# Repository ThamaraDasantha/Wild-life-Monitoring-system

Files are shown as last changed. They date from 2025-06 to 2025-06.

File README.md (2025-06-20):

# 🐾 Wildlife Monitoring System for Development in Tourism

This project introduces a **solar-powered, real-time wildlife monitoring system** that enhances tourism by providing live animal detection, classification, and notifications through a mobile app. The system leverages edge computing, AI, and long-range wireless communication to deliver efficient and scalable wildlife monitoring in remote areas.

---

## 🎯 Project Objectives

- Boost eco-tourism by enabling real-time wildlife sightings.
- Enhance conservation through automated monitoring.
- Provide a user-friendly experience via a dedicated mobile application.
- Support wildlife-related research and law enforcement with data analytics.

---

## 🔧 Key Technologies

| Feature | Description |
|---|---|
| **Animal Detection** | Real-time CNN-based species classification on captured images |
| **Edge Computing** | Raspberry Pi Zero2W perform local processing |
| **Power Management** | STM32 Microcontorller for Power Management |
| **Power Source** | Solar-powered units with rechargeable backup batteries |
| **Communication** | Long-range LoRa WAN to central hub, Bluetooth for mobile device connection |
| **Mobile App** | Displays animal sightings, real-time alerts, navigation support |
| **Smart Algorithms** | Optimizes vehicle paths for tourist flow, efficiency, and safety |
| **Database Integration** | Centralized storage for research, anti-poaching, and wildlife conflict prevention |

---

## 📐 System Architecture

```
[Motion Sensor] ──> [STM32] ──> [Raspberry Pi] ──> CNN [Local Decision Making]
                                   ↓
                            LoRa Transmission
                                   ↓
                            [Central Hub] ──>[Database]
                                   ↓
                            [Vehical Module (Lora to Blutooth Interfacing)]
                                   ↓
                             [App Backend]
```

---

## 📲 Mobile Application Features

- 📸 Live animal detection alerts
- 📍 Wildlife location navigation
- 🐅 Animal type filter & sighting history
- 🌐 Connected via Bluetooth to nearby monitoring nodes or central hub

---

## 🌍 Real-World Impact

- **Tourism**: Improves visitor experience with real-time encounters.
- **Research**: Data logging enables pattern analysis and habitat studies.
- **Conservation**: Supports anti-poaching strategies and conflict mitigation.
- **Sustainability**: Operates off-grid using solar energy.

---

## 👥 Authors & Acknowledgments

- **Thamara Banneheka**, ** Isuru Abhayarathne**, **Dinith Wanniarachchi**  
  Department of Electrical and Electronic Engineering, SLIIT  
- Supervised by: *Shehani Jayasinghe, Dr. Eranga Wijesinghe, Dr. Nushara Wedasingha*

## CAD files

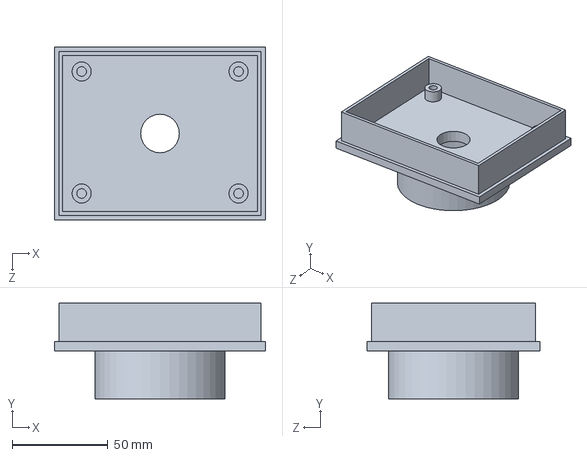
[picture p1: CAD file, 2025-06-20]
Tracker Module/Enclouser/Traker module.SLDASM
110.0 x 50.0 x 90.0 mm

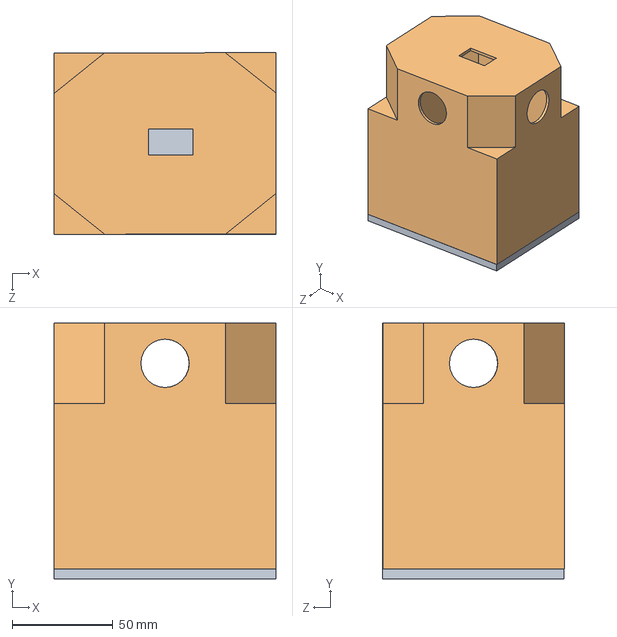
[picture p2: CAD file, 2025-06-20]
Tracker Module/Enclouser/Assem1.SLDASM
110.1 x 127.0 x 90.1 mm
BOTTOM_Part
TOP_PART

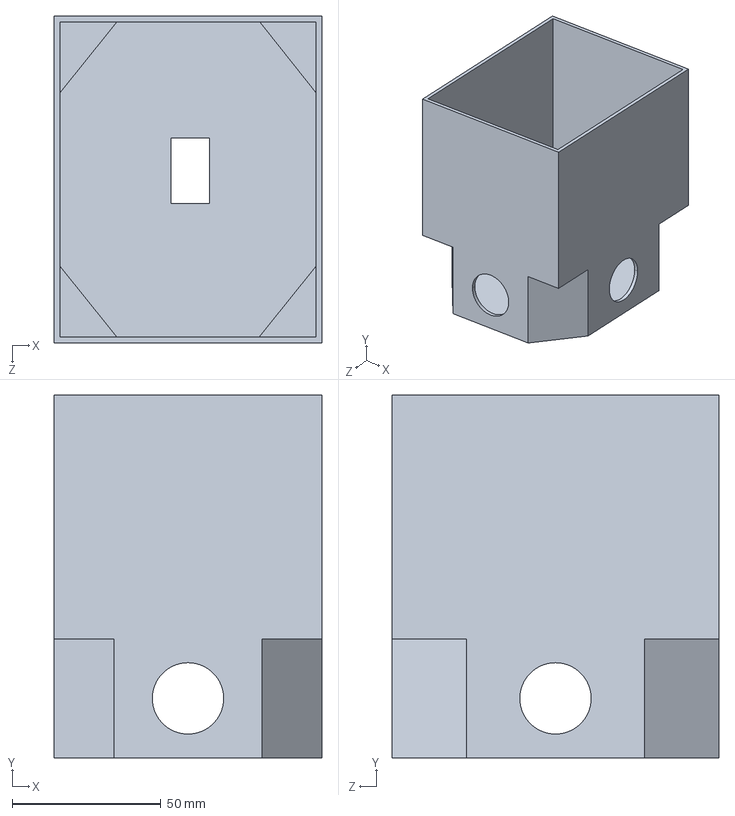
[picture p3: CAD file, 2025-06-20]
Tracker Module/Enclouser/TOP_PART.STEP
90.0 x 122.0 x 110.0 mm

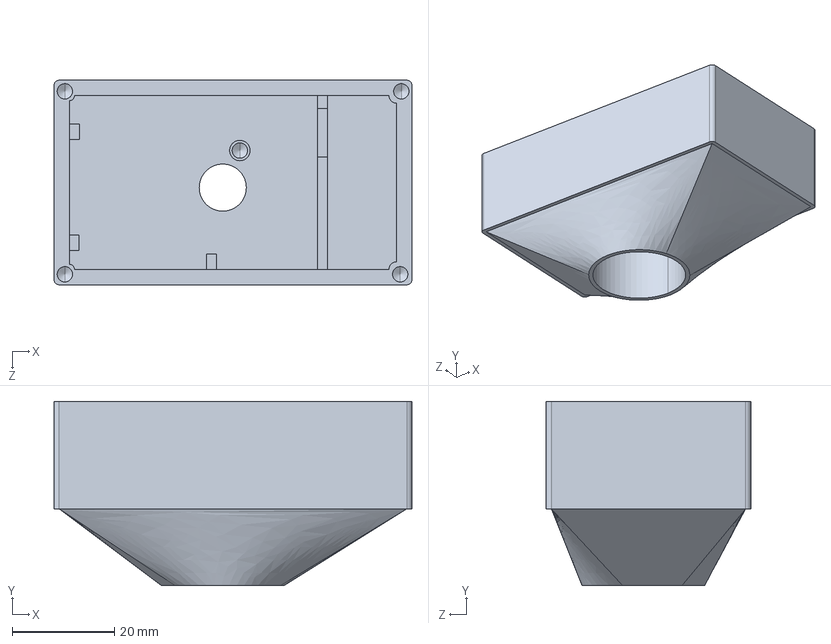
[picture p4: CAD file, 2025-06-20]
Vehical Module/3D models/BOX.STEP
70.0 x 36.0 x 40.0 mm

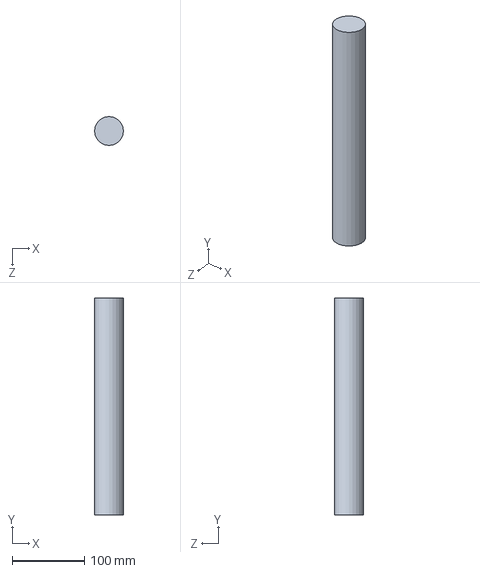
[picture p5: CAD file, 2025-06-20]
Tracker Module/Enclouser/Part1.SLDPRT
40.0 x 300.0 x 40.0 mm

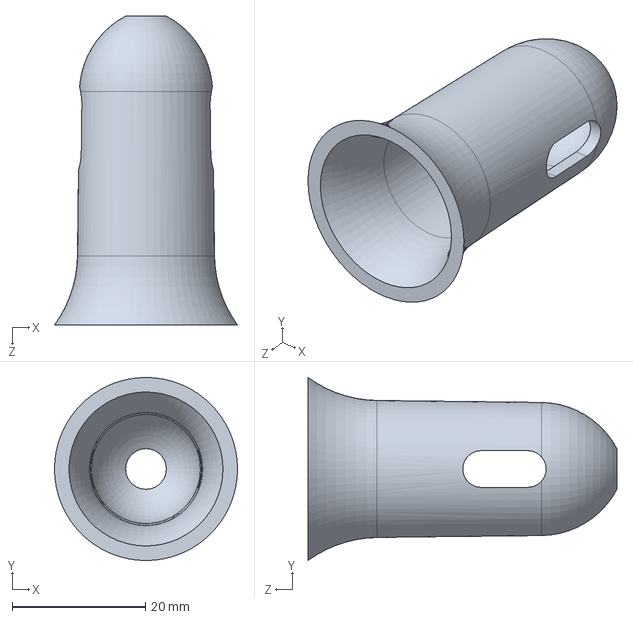
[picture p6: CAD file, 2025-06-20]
Vehical Module/3D models/Encasing Body 1.SLDPRT
27.5 x 27.5 x 46.4 mm

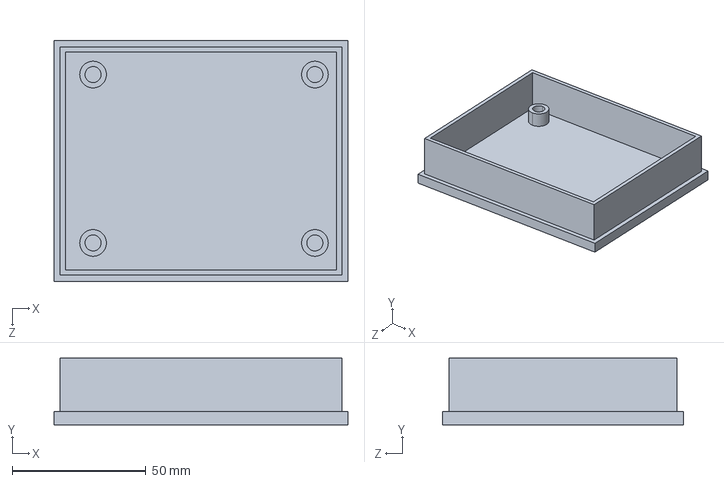
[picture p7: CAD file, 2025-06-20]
Tracker Module/Enclouser/BOTTOM_Part.STEP
110.0 x 25.0 x 90.0 mm

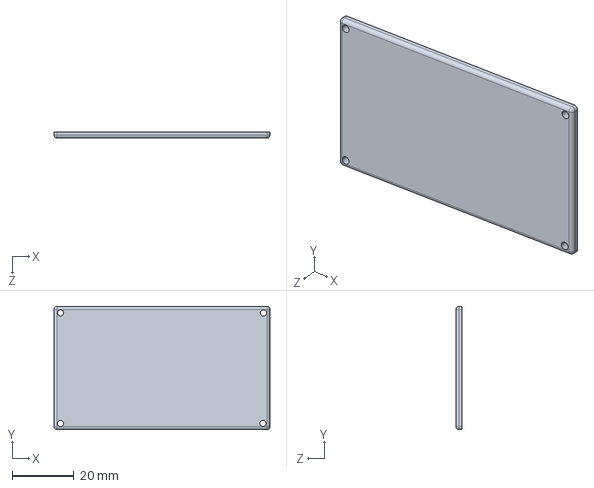
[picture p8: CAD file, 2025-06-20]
Vehical Module/3D models/Part1.STEP
70.0 x 40.0 x 2.00 mm

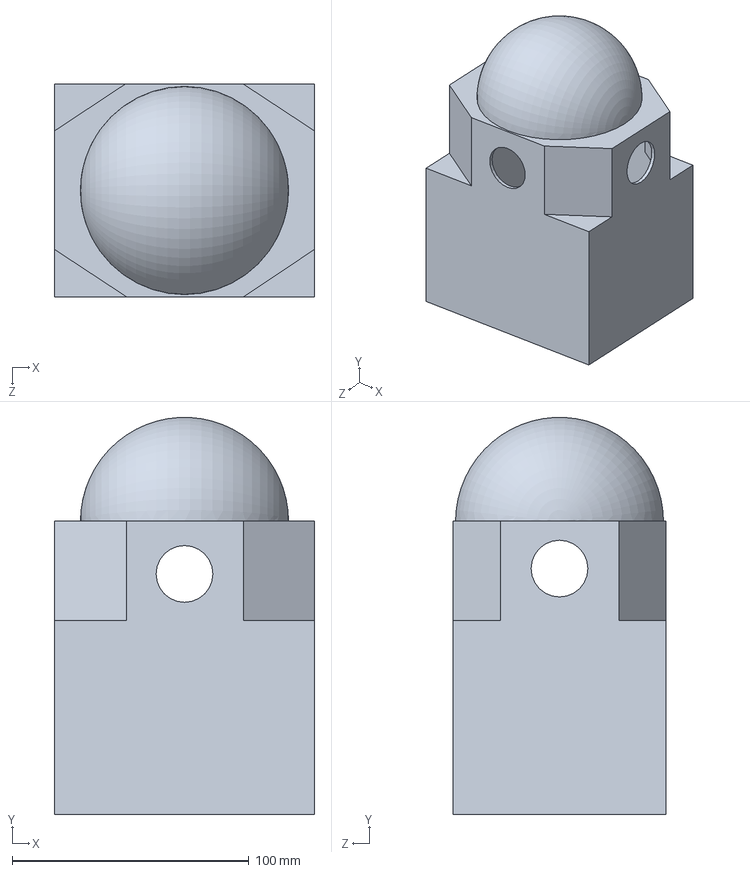
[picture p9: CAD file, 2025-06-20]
Tracker Module/Enclouser/V2.SLDPRT
110.0 x 167.9 x 90.0 mm

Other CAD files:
Tracker Module/Enclouser/BOTTOM V2.SLDPRT
Tracker Module/Enclouser/BOTTOM_Part.SLDPRT
Tracker Module/Enclouser/TOP_PART.SLDPRT
Tracker Module/Enclouser/makeProjectedPlanarWire.x_t
Vehical Module/3D models/BOX.SLDPRT
Vehical Module/3D models/BOX.STL
Vehical Module/3D models/Part1.STL
Vehical Module/3D models/makeProjectedPlanarWire.x_t

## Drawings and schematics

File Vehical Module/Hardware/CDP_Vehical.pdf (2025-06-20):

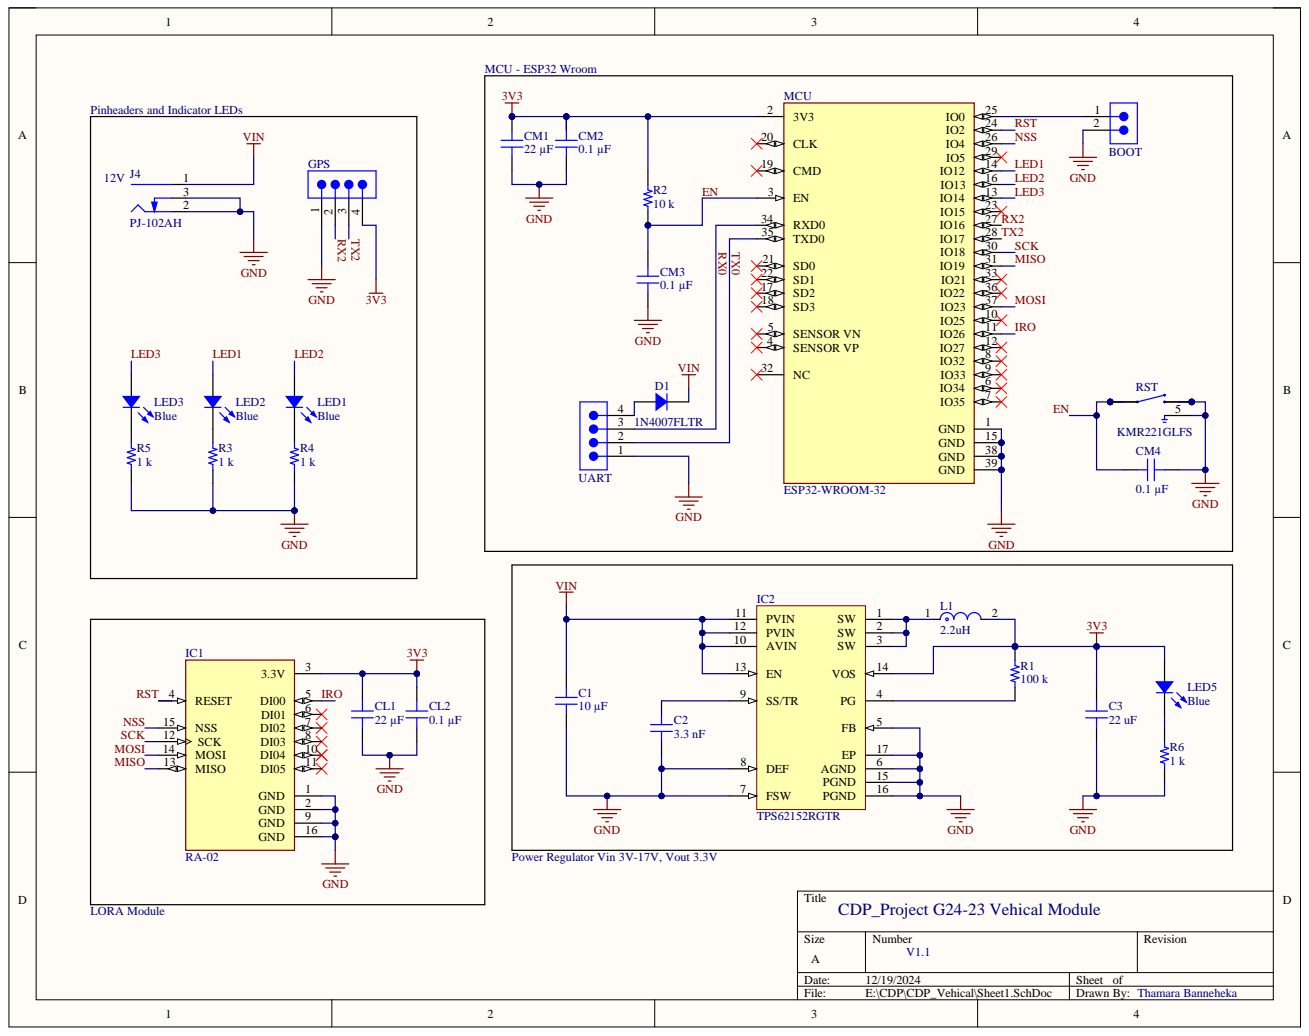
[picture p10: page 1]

Pinheaders and Indicator LEDs

Power Regulator Vin 3V-17V, Vout 3.3V

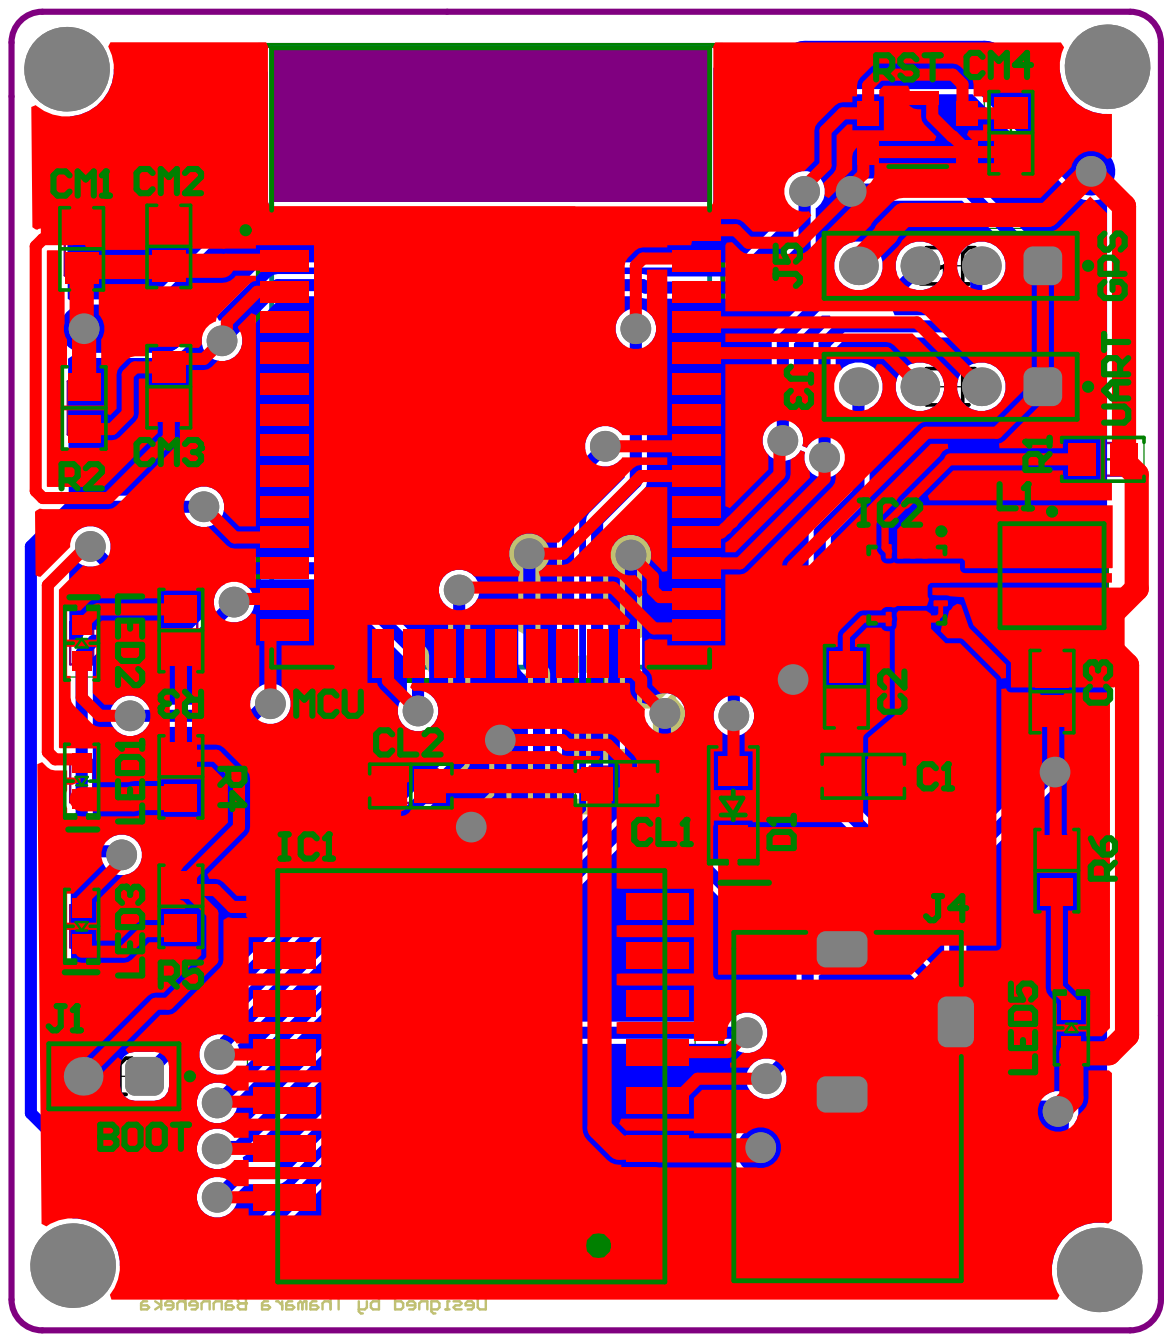
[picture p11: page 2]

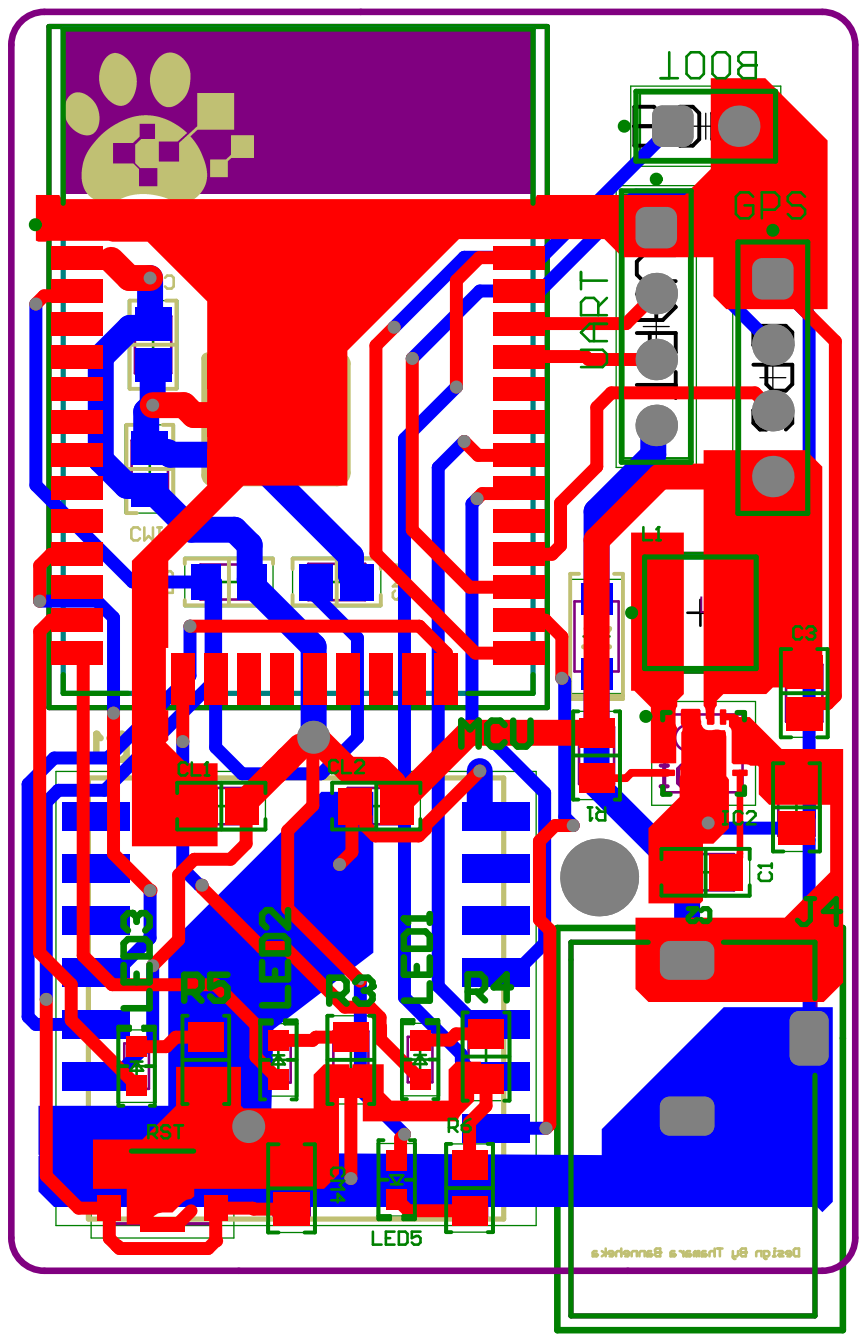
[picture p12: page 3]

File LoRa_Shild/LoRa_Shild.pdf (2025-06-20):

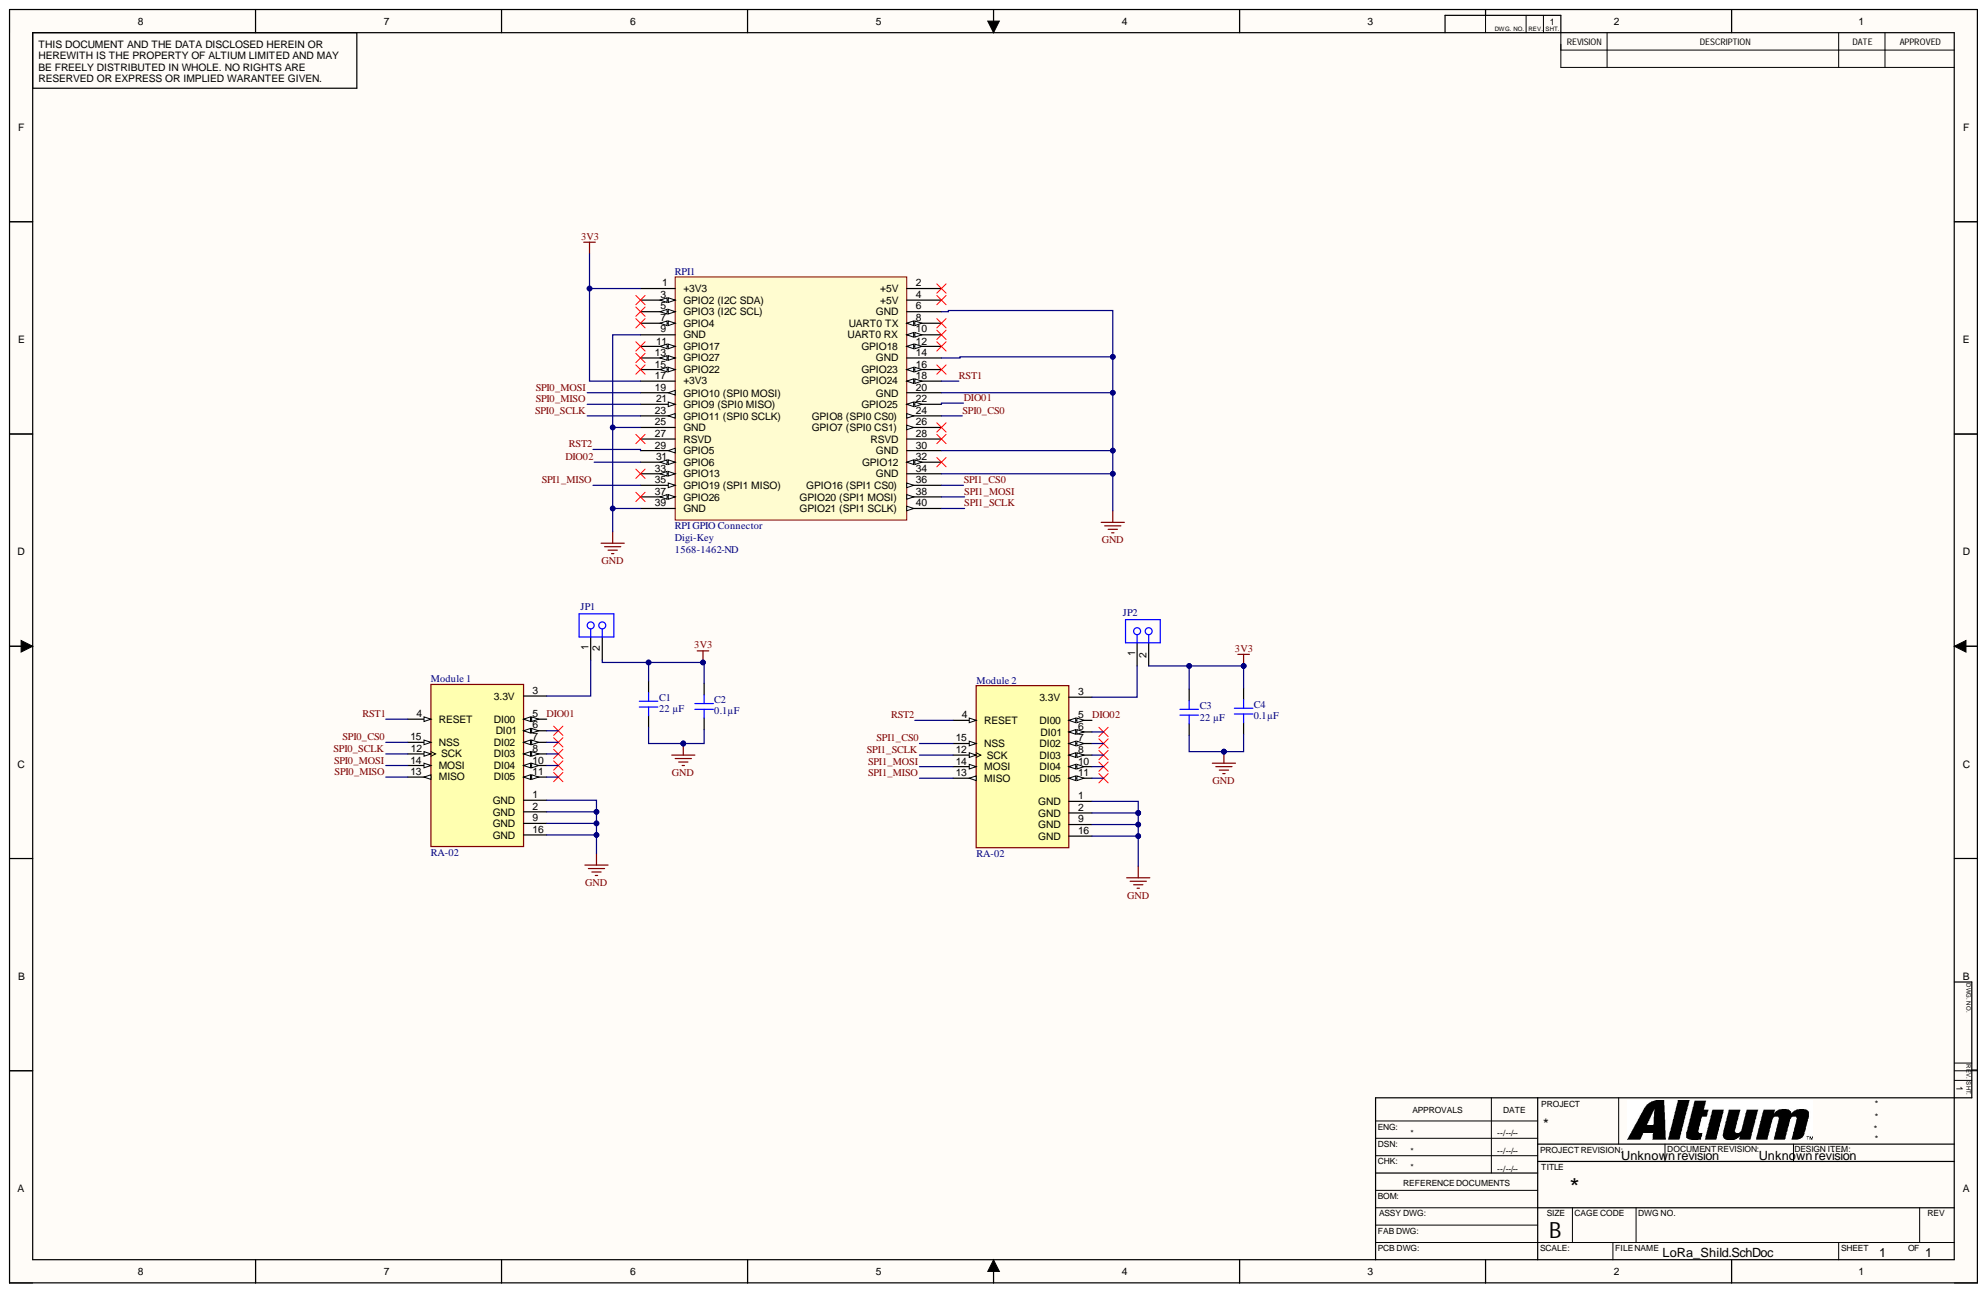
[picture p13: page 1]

8 | 7 | 6 | 5 | 4 | 3 | DWG. NO. | REV. | 1 SHT. | 2 | 1

THIS DOCUMENT AND THE DATA DISCLOSED HEREIN OR HEREWITH IS THE PROPERTY OF ALTIUM LIMITED AND MAY BE FREELY DISTRIBUTED IN WHOLE. NO RIGHTS ARE RESERVED OR EXPRESS OR IMPLIED WARANTEE GIVEN. | 3V3 | REVISION | DESCRIPTION | DATE | APPROVED

REV. SHT. DWG. NO.

DATE | PROJECT * | * * APPROVALS * *

ENG: * | --/--/--

DSN: * | --/--/--

PROJECT REVISION: Unknown revision | DOCUMENT REVISION: Unknown revision | DESIGN ITEM:

CHK: * | --/--/--

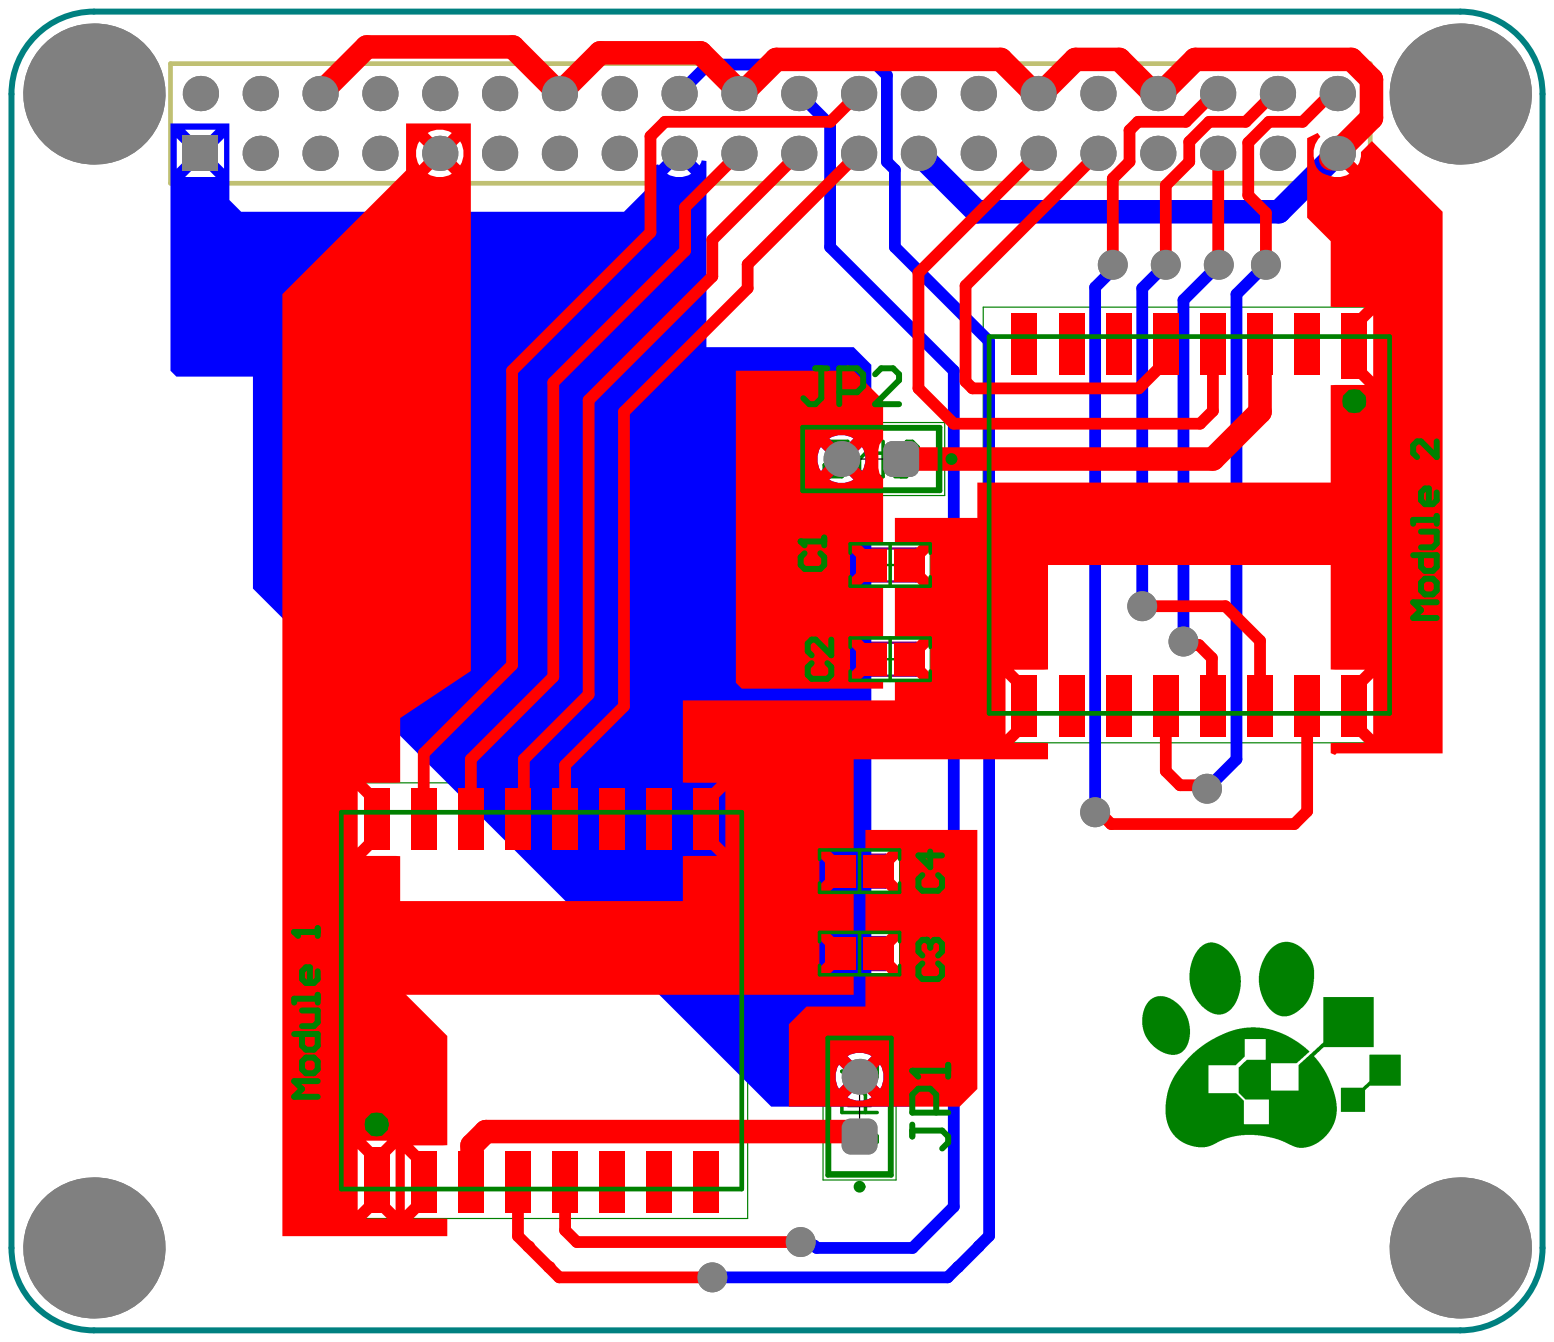
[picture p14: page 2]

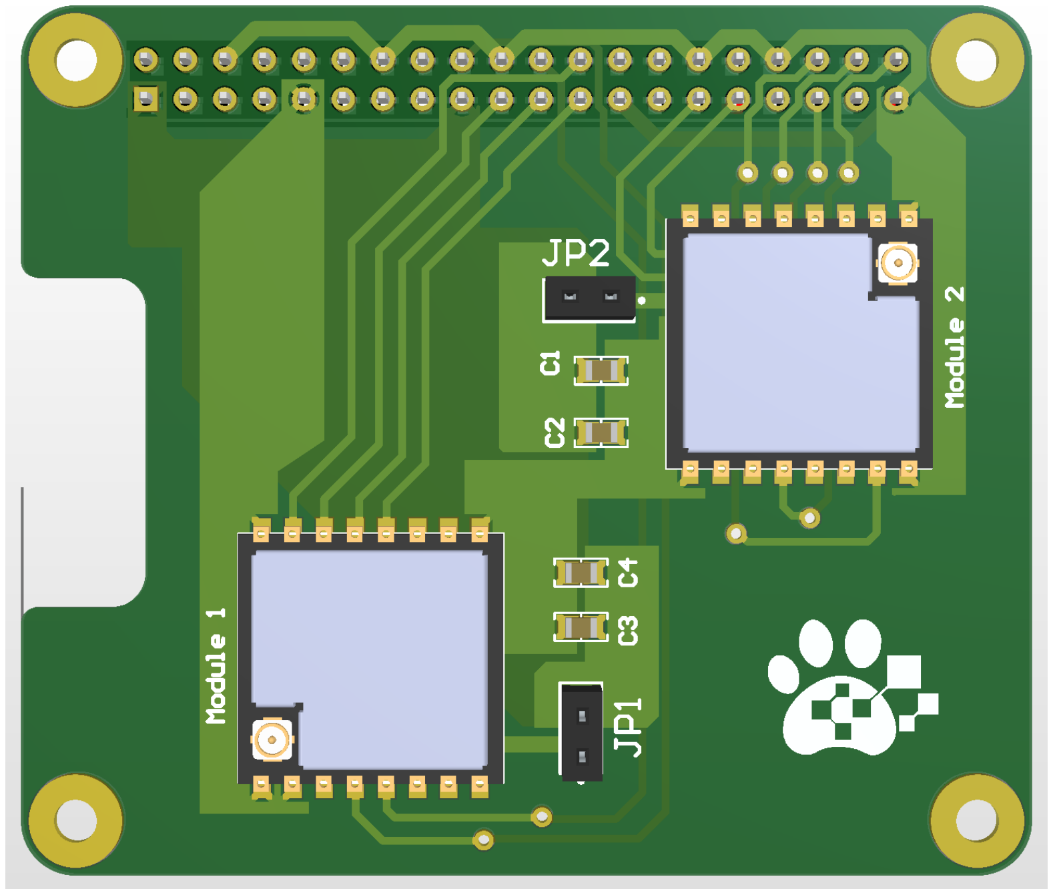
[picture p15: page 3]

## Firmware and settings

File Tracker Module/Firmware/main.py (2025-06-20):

import os
import numpy as np
import tflite_runtime.interpreter as tflite
from PIL import Image

# isuru start---------------------------------------------------------------------------------------------------------------
import serial
import smbus
from gpiozero import AngularServo
from gpiozero import LED
from time import sleep
import subprocess
from LoRaRF import SX127x, LoRaSpi, LoRaGpio
import time

# Load the TFLite model
MODEL_PATH = "Model/animal_model2.tflite"  # Change this to your actual model file path
interpreter = tflite.Interpreter(model_path=MODEL_PATH)
interpreter.allocate_tensors()

# Get input and output details
input_details = interpreter.get_input_details()
output_details = interpreter.get_output_details()

# Define class labels
LABELS = ["bear", "deer", "elephant", "leopard", "peacock"]

# Initialize LoRa transmitter
spi = LoRaSpi(0, 0)
cs = LoRaGpio(0, 8)
reset = LoRaGpio(0, 22)
LoRa = SX127x(spi, cs, reset)

if not LoRa.begin():
    raise Exception("Failed to initialize LoRa")

LoRa.setFrequency(433000000)
LoRa.setTxPower(17, LoRa.TX_POWER_PA_BOOST)
LoRa.setSpreadingFactor(7)
LoRa.setBandwidth(125000)
LoRa.setCodeRate(5)
LoRa.setHeaderType(LoRa.HEADER_EXPLICIT)
LoRa.setPreambleLength(12)
LoRa.setPayloadLength(50)
LoRa.setCrcEnable(True)
LoRa.setSyncWord(0x35)

def send_data_via_lora(animal_name, latitude, longitude):
    message = f"Animal: {animal_name}, Lat: {latitude}, Lon: {longitude}\0"
    message_list = [ord(c) for c in message]

    LoRa.beginPacket()
    LoRa.write(message_list, len(message_list))
    LoRa.endPacket()
    print(f"Transmitted: {message}")

# Configure the serial connection
ser = serial.Serial(
    port='/dev/ttyS0',
    baudrate=115200,
    parity=serial.PARITY_NONE,
    stopbits=serial.STOPBITS_ONE,
    bytesize=serial.EIGHTBITS,
    timeout=1
)

# SoC init start--------------
threshold=15.0  # Battery Low threshold in % 
address = 0x36  # I2C-Adddress of MAX17043

#registers
VCELL_REGISTER=0x02
SOC_REGISTER=0x04
MODE_REGISTER=0x06
VERSION_REGISTER=0x08
CONFIG_REGISTER=0x0C
COMMAND_REGISTER=0xFE

#  open the bus by creating an instance
MAX17043 = smbus.SMBus(1)

def reset():
    MAX17043.write_byte_data(address, COMMAND_REGISTER, 0x00)
    MAX17043.write_byte_data(address, COMMAND_REGISTER, 0x54)
 
def quickStart():
    MAX17043.write_byte_data(address, MODE_REGISTER, 0x40)
    MAX17043.write_byte_data(address, MODE_REGISTER, 0x00)

def getVersion():
    print (hex ( MAX17043.read_word_data(address, VERSION_REGISTER))) 

def getSOC():
    MSB= MAX17043.read_byte_data(address, SOC_REGISTER)
    LSB = MAX17043.read_byte_data(address, SOC_REGISTER)
    percentage= MSB+ LSB/256.0
    print(f"Battery SoC: {percentage}%")
    if percentage < threshold:
        print("Battery Low")
        #os.system("sudo shutdown -h now")

'''def getSOCarduino():
    #float percent;
    soc = MAX17043.read_word_data(address, SOC_REGISTER)
    percent = (float)((soc & 0xFF00) >> 8)
    percent += ((float)(soc & 0x00FF)) / 256.0

    print(f"Battery SoC: {percent}%")
''' 
 
def getVolt():
    vCell = MAX17043.read_word_data(address, VCELL_REGISTER)
    vCell = (vCell) >> 4
    divider = 4096.0 / 5.12
    voltage = (vCell) / divider
    print(f"Battery voltage: {voltage}V")

# SoC init end----------------
    
# Initialize the servo on GPIO17
# min_angle and max_angle parameters set the range of motion
# min_pulse_width and max_pulse_width might need adjustment for the specific servo
servo = AngularServo(17, 
                     min_angle=0, 
                     max_angle=180,
                     min_pulse_width=0.0005,  # 0.5ms
                     max_pulse_width=0.0025)  # 2.5ms

#servo reset
servo.angle = 90
sleep(0.5)
servo.detach()

#SoC reset
reset()
quickStart()
#getVersion()

#RPi status
RPi_status = LED(24)
RPi_status.on()

# Create a directory for the photos if it doesn't exist
output_dir = 'photos'
os.makedirs(output_dir, exist_ok=True)

def take_photo(angle):
    # Construct the filename based on the angle
    filename = os.path.join(output_dir, f'photo_animal.jpg')
    # Capture the image using libcamera-still
    subprocess.run(['libcamera-still', '-o', filename])
    print(f'Took photo at {angle} degrees')

def turn_servo(PIR):
	if PIR > 0:
		SerAngle = (PIR - 1)*90
		servo.angle = SerAngle
		sleep(0.5)
		servo.detach()
		sleep(0.5)
		take_photo(SerAngle)
	else:
		servo.angle = 0
		sleep(0.5)
		servo.detach()
		print("Invalid PIR")

#print(f"Waiting for UART data")
#ser.write(b'\x01')
         
# isuru end ----------------------------------------------------------------------------------------------------------------------------        


def preprocess_image(image_path, input_shape):
    """Prepares the image for model inference."""
    image = Image.open(image_path).convert("RGB")  # Convert to RGB (if not already)
    image = image.resize((input_shape[1], input_shape[2]))  # Resize to model's input size
    image = np.array(image, dtype=np.float32) / 255.0  # Normalize pixel values to [0,1]
    image = np.expand_dims(image, axis=0)  # Add batch dimension
    return image

def classify_image(image_path):
    """Classifies an image using the TFLite model."""
    input_shape = input_details[0]['shape']
    image_data = preprocess_image(image_path, input_shape)

    # Set the input tensor
    interpreter.set_tensor(input_details[0]['index'], image_data)

    # Run inference
    interpreter.invoke()

    # Get the output tensor
    output_data = interpreter.get_tensor(output_details[0]['index'])[0]
    predicted_index = np.argmax(output_data)
    predicted_label = LABELS[predicted_index]
    confidence = output_data[predicted_index]

    print(f"Animal type: {predicted_label} ({confidence:.2f})")
    return predicted_label, confidence


def get_location():
    # Dummy location, replace with GPS module integration if available
    latitude = 7.915590  # Example latitude
    longitude = 80.973904 # Example longitude
    return latitude, longitude

#ser.write(b'\x04') #to reset the stm32 when debugging, comment otherwise

# Main function
while True:
    # Continuously read and process the data from the STM32
    #while ser.in_waiting <= 0:
    print(f"Waiting for PIR")
    RPi_status.on()
    ser.write(b'\x01')
    
    #sleep(1)
    
    if ser.in_waiting > 0:
        detected_pir = ser.read()[0]
        print(f"Detected PIR: {detected_pir}")
        sleep(0.5)
        
        turn_servo(detected_pir)
        take_photo((detected_pir - 1)*90)
        
        
        image_path = "/home/tham/Documents/CDP/photos/photo_animal.jpg"  
        animal_name = classify_image(image_path)
        

        latitude, longitude = get_location()
        print(f"Latitude: {latitude}, Longitude: {longitude}")

        # Transmit Data via LoRa
        message = f"{animal_name},{latitude:.4f},{longitude:.4f}"
        message_bytes = list(message.encode())
        print(f"Transmitting: {message}")

        LoRa.beginPacket()
        LoRa.write(message_bytes, len(message_bytes))
        LoRa.endPacket()
        LoRa.wait()
        print("Data transmitted successfully")
    
        getSOC()
        #getVolt()
        sleep(10)  # Small delay before shutdown
        
        print("Shuting down")
        #servo reset
        servo.angle = 90
        sleep(0.5)
        servo.detach()
        RPi_status.off()
        #os.system("sudo shutdown now")    
    sleep(1)

#if __name__ == "__main__":
#    main()

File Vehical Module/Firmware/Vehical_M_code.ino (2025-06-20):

#include "BluetoothSerial.h"
#include "LoRa.h"

#define ledpin1 12  // LED 1 for Bluetooth connectivity
#define ledpin2 13  // LED 2 for LoRa sending debug
#define ledpin3 14  // LED 3 for LoRa receiving debug

// Create BluetoothSerial object
BluetoothSerial SerialBT;

// Variable to check if Bluetooth is connected
bool isConnected = false;

// LoRa configurations
#define LORA_SS 2  // LoRa chip select
#define LORA_RST 4  // LoRa reset
#define LORA_DIO0 26 // LoRa DIO0

void setup() {
  // Initialize Serial Monitor
  Serial.begin(115200);

  // Initialize Bluetooth Serial 
  SerialBT.begin("Trailguide");  
  Serial.println("Bluetooth device is ready to pair");

  // Register Bluetooth callback
  SerialBT.register_callback(btCallback);

  // Initialize LED pins
  pinMode(ledpin1, OUTPUT);
  pinMode(ledpin2, OUTPUT);
  pinMode(ledpin3, OUTPUT);

  // Initialize LoRa module
  LoRa.setPins(LORA_SS, LORA_RST, LORA_DIO0);
  if (!LoRa.begin(915E6)) { // Set LoRa frequency (915 MHz here)
    Serial.println("Starting LoRa failed!");
    digitalWrite(ledpin3, HIGH);
    while (1);
  }
  Serial.println("LoRa initialized");
  digitalWrite(ledpin2, HIGH);
}

void loop() {
  // Check if Bluetooth is connected
  if (isConnected) {
    // Read data from Bluetooth
    if (SerialBT.available()) {
      String incomingData = SerialBT.readString();
      Serial.print("Received from Bluetooth: ");
      Serial.println(incomingData);

      // Send the Bluetooth message over LoRa
      sendLoRaMessage(incomingData);
    }
    
    // Send sample data via Bluetooth and LoRa
    sampledata();

  } else {
    Serial.println("Waiting for Bluetooth connection...");
    ledblink1();
  }

  // Check if there's incoming data from LoRa
  if (LoRa.parsePacket()) {
    String receivedLoRaMessage = "";
    while (LoRa.available()) {
      receivedLoRaMessage += (char)LoRa.read();
    }
    Serial.print("Received from LoRa: ");
    Serial.println(receivedLoRaMessage);

    // Blink LED 3 to indicate LoRa reception
    ledblink3();

    // Send the LoRa message to Bluetooth
    if (isConnected) {
      SerialBT.println(receivedLoRaMessage);
    }
  }
}

// Callback function to handle Bluetooth connection events
void btCallback(esp_spp_cb_event_t event, esp_spp_cb_param_t *param) {
  if (event == ESP_SPP_SRV_OPEN_EVT) {
    Serial.println("Bluetooth connected!");
    digitalWrite(ledpin1, HIGH);
    isConnected = true;
  } else if (event == ESP_SPP_CLOSE_EVT) {
    Serial.println("Bluetooth disconnected!");
    digitalWrite(ledpin1, LOW);
    isConnected = false;
  }
}

void sampledata() {
  // Sample data to send (can be dynamic or based on real inputs)
  String animalType = "Bear";
  float latitude = 6.927079;
  float longitude = 79.861244;

  // Format the message to send in the required format
  String message = animalType + "," + String(latitude, 6) + "," + String(longitude, 6);

  // Send the message via Bluetooth
  SerialBT.println(message);
  Serial.println("Message sent to Bluetooth");

  // Send the same message via LoRa
  sendLoRaMessage(message);

  delay(10000); // Send the message every 10 seconds for testing
}

// Function to send messages via LoRa
void sendLoRaMessage(String message) {
  LoRa.beginPacket();
  LoRa.print(message);
  LoRa.endPacket();
  Serial.println("Message sent to LoRa");

  // Blink LED 2 to indicate LoRa sending
  ledblink2();
}

void ledblink1() {  
  digitalWrite(ledpin1, HIGH);
  delay(500); 
  digitalWrite(ledpin1, LOW);
  delay(500); 
}

void ledblink2() {
  digitalWrite(ledpin2, HIGH);
  delay(100); 
  digitalWrite(ledpin2, LOW);
}

void ledblink3() {
  digitalWrite(ledpin3, HIGH);
  delay(100); 
  digitalWrite(ledpin3, LOW);
}
